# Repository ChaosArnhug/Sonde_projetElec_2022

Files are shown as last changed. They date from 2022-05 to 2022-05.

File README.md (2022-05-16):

# Projet d'électonique 2022
Ce répo regroupe le code, les schémas Eagle et le Prothéus du projet d'électonique à l'Ephec en 2022 pour les 2ièmes années.

## Contexte 

* Les PIC’s deviennent avec le temps des composants universels des systèmes électroniques et des systèmes embarqués. Il semble donc opportun que les étudiants soient aptes à définir et développer une carte comportant non seulement un microcontrôleur PIC mais aussi les composants annexes minimaux nécessaires au bon fonctionnement de ce dernier

*  De manière à pouvoir ensuite tester et vérifier le bon fonctionnement de la carte PIC, il semble opportun de développer une application électronique se basant, au moinspour certaines de ses fonctions, sur le PIC

* Cette application sera un télémètre à ultrasons qui envoie auPIC la mesure d’une distance en cm

* La carte doit afficher la distance sur 2 afficheurs 7-segments

* La carte devra signaler une alerte lorsque la distance dépasse (ou tombe en dessous d’) un seuil critique défini par l’utilisateur

* Enfin, pour utiliser les connaissances du cours de Développement informatique II, le PIC devra communiquer avec une application PYTHON qui affichera la distance
mesurée et permettra de définir le seuil de déclenchement d’alerte

## Spécifications

* PIC : 18F458

* Sonde : HC-SR04

* Affichage distance : 2 7-segments à cathodes communes 

* Affichage alerte : LED rouge qui clignote

* Affichage aucune alerte : LED verte

* Gestion du seuil : interface codée en Python

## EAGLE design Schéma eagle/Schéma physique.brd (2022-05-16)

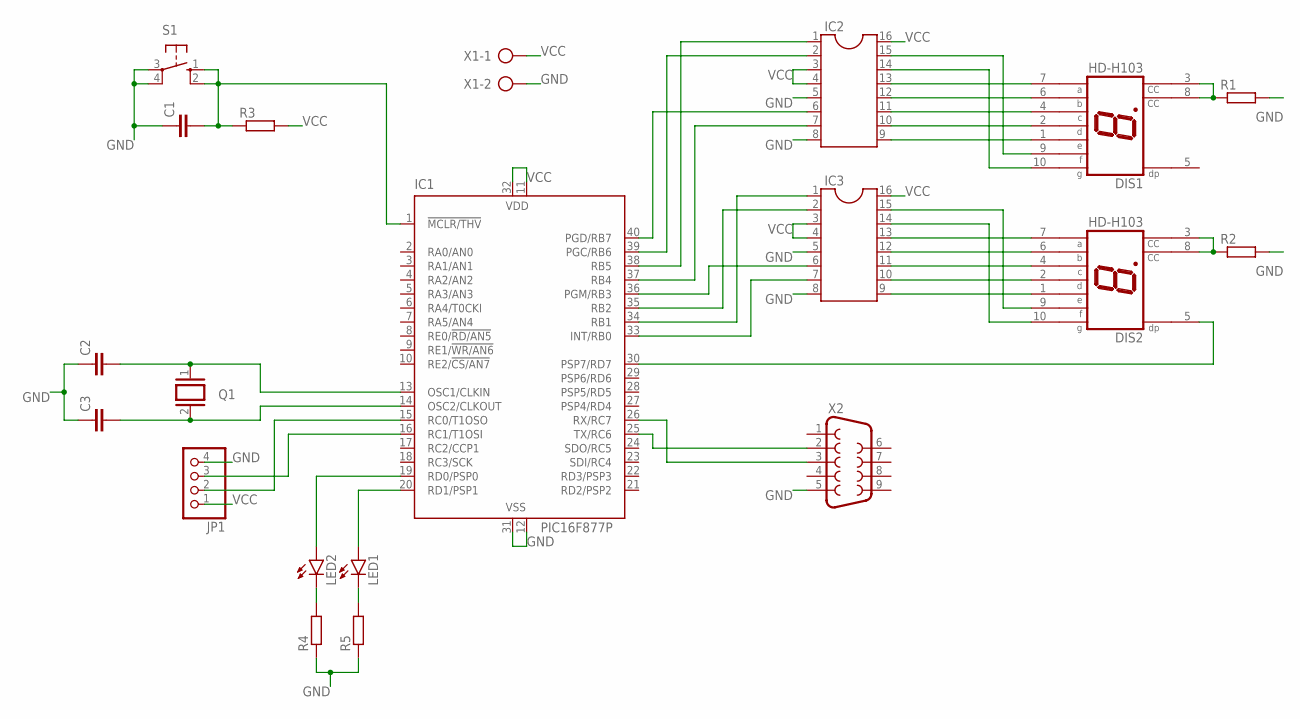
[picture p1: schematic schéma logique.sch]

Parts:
C1, C2, C3: C-EU025-025X050; C025-025X050
DIS1, DIS2: HD-H103; HDSP-M
IC1: PIC16F877P; DIL40
IC2, IC3: DIL16
JP1: PINHD-1X4; 1X04
LED1, LED2: LED5MM
Q1: XTAL/S; QS
R1, R2, R3, R4, R5: R-EU_0207/10; 0207/10
S1: 10-XX; B3F-10XX
X1: AK300/2
X2: F09H

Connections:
GND: C1.1, C2.1, C3.1, IC1.12 (VSS), IC1.31 (VSS), IC2.5, IC2.8, IC3.5, IC3.8, JP1.4, R1.2, R2.2, R4.1, R5.1, S1.3, S1.4 (P1), X1.2, X2.5
unnamed: IC1.25 (TX/RC6), X2.2
unnamed: IC1.26 (RX/RC7), X2.3
unnamed: IC1.33 (INT/RB0), IC3.7
unnamed: IC1.34 (RB1), IC3.1
unnamed: IC1.35 (RB2), IC3.2
unnamed: IC1.36 (PGM/RB3), IC3.6
unnamed: IC1.37 (RB4), IC2.7
unnamed: IC1.38 (RB5), IC2.1
unnamed: IC1.39 (PGC/RB6), IC2.2
unnamed: IC1.40 (PGD/RB7), IC2.6
unnamed: DIS1.7 (A), IC2.13
unnamed: DIS1.6 (B), IC2.12
unnamed: DIS1.4 (C), IC2.11
unnamed: DIS1.2 (D), IC2.10
unnamed: DIS1.1 (E), IC2.9
unnamed: DIS1.9 (F), IC2.15
unnamed: DIS1.10 (G), IC2.14
unnamed: DIS2.7 (A), IC3.13
unnamed: DIS2.6 (B), IC3.12
unnamed: DIS2.4 (C), IC3.11
unnamed: DIS2.2 (D), IC3.10
unnamed: DIS2.1 (E), IC3.9
unnamed: DIS2.9 (F), IC3.15
unnamed: DIS2.10 (G), IC3.14
unnamed: DIS1.3 (CC), DIS1.8 (CC), R1.1
unnamed: DIS2.3 (CC), DIS2.8 (CC), R2.1
unnamed: DIS2.5 (DP), IC1.30 (PSP7/RD7)
unnamed: C1.2, IC1.1 (!MCLR/THV), R3.1, S1.1 (S), S1.2 (S1)
unnamed: C2.2, IC1.13 (OSC1/CLKIN), Q1.1
unnamed: C3.2, IC1.14 (OSC2/CLKOUT), Q1.2
unnamed: IC1.15 (RC0/T1OSO), JP1.2
unnamed: IC1.16 (RC1/T1OSI), JP1.3
unnamed: IC1.19 (RD0/PSP0), LED2.A
unnamed: IC1.20 (RD1/PSP1), LED1.A
unnamed: LED2.K (C), R4.2
unnamed: LED1.K (C), R5.2
VCC: IC1.11 (VDD), IC1.32 (VDD), IC2.3, IC2.4, IC2.16, IC3.3, IC3.4, IC3.16, JP1.1, R3.2, X1.1

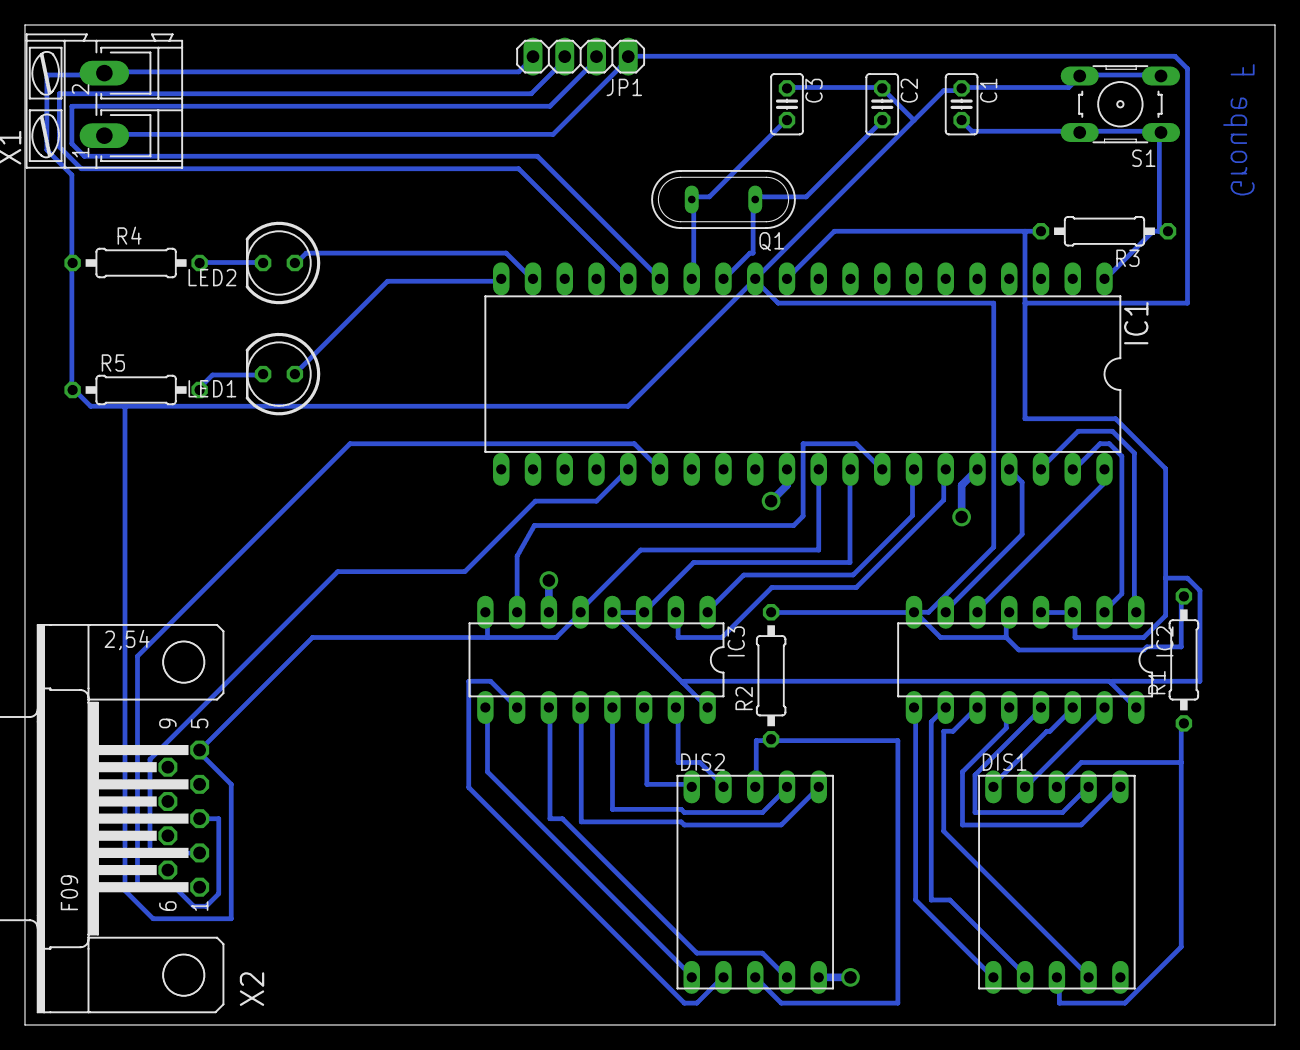
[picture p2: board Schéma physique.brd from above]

Board: 2 copper layers, 100.0 x 80.0 mm, 20 parts (0 on the bottom side), 38 nets.

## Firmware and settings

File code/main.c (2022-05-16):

#include <main.h>
#include <stdio.h>
#use rs232(baud=9600, xmit=PIN_C6, rcv=PIN_C7, ERRORS)

//communication avec port COM
int flag_threshold = 0; //flag on si nouveau seuil
char *buffer[4]; // 4 car cara dï¿½but trame + seuil (max = 999) ==> ex: @954 ou @001 ou @051
int buf_compteur = 0;
char *trame_start = "@";

#INT_RDA
void  RDA_isr(void)
{
   buffer[buf_compteur] = getc();   //lis le caractï¿½re ï¿½ la position courante du flux de donnï¿½es
   trame_start = buffer[0];
   if (strcmp(buffer[0], trame_start) == 0 && flag_threshold == 0){   //si trame commence par @ et qu'on ne traite pas dï¿½jï¿½ un nouveau seuil
      buf_compteur ++;
      if (buf_compteur >= 4){    //Traitement quand buffer plein
         buf_compteur = 0;
         flag_threshold = 1;
      }
   }
}

void main()
{
   //init variable
   int16 threshold;
   long duration;
   int16 distance;
   int poids_fort;
   int poids_faible;

   setup_timer_0(RTCC_INTERNAL);
   enable_interrupts(INT_RDA);
   enable_interrupts(GLOBAL);
   setup_low_volt_detect(FALSE);

   while(1)
   {
      //Initialization + être sure que trigger est off
      output_low(PIN_C0);
      delay_ms(300);
      
      //Prise d'une mesure
      output_high(PIN_C0);
      delay_us(300);
      output_low(PIN_C0);
      
      //Attend un output
      while(!input(PIN_C1)){}
      set_timer0(0);

      
      //Attend que l'output se termine
      while(input(PIN_C1)){}
      duration = (long)get_timer0();
      distance = (int16)(duration / 145);
      
          //Affichage
      if (distance >= 1000){ //Overflow ou distance négative = erreur
         output_b(0);
         output_high(PIN_D7); //affiche juste un point 

      }
      else if (distance >= 100){ // affichage passe en metre
         
         poids_fort = (int)(distance / 100);
         poids_faible = (int)((distance % 100) / 10);
         
         output_high(PIN_D7);
         output_b((poids_faible << 4) + poids_fort); //Decalage de 4 vers la doite à cause du montage physique et logique
 
      }
      else { //affichage en centimetre
      
         poids_fort = (int)distance / 10;
         poids_faible = (int)distance % 10;
         
         output_low(PIN_D7);
         output_b((poids_faible << 4) + poids_fort);
      }
      
      // Nouveau seuil
      if(flag_threshold){  //Calcul nouveau seuil (char - 48 => convert char to int)
         int16 a = buffer[1] - 48;
         int16 b = buffer[2] - 48;
         int16 c = buffer[3] - 48;
         threshold = (int16)((a*100)+(b*10)+c);
         flag_threshold = 0;

      } 
      
      if(threshold == NULL){  //valeur par defaut 
         threshold = 50;

      }
      
      //Alerte
      if(threshold < distance){
         output_high(PIN_D1); //alume led verte
         output_low(PIN_D0);

      }
      if(threshold > distance){
         output_low(PIN_D1); //Coupe led verte
         output_toggle(PIN_D0); //Clignote led red
       
      }
     
   }
}

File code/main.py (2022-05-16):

import tkinter.messagebox
from tkinter import *
import serial
import time
import threading

ser = serial.Serial('COM1', baudrate=9600, timeout=1)
run = True

'''
Functions ##############################################################################################################
'''


def writeOnPort():
    resp = e1.get()
    if (verifString(resp) == True):
        ser.write(resp.encode())
        tkinter.messagebox.showinfo(title="Réussi !", message="Le nouveau seuil de déclenchement à été défini !")
    else :
        tkinter.messagebox.showwarning(title="Erreur", message="Le seuil de déclenchement doit être écris de cette manière :\n @123 \n(si la valeur est inférieur à 100cm, il faut indiquer un 0 (exemple : 090) \n ATTENTION : La valeur ne doit pas excéder 400cm !")
    print(resp)


def verifString(test):
    test_sans = test[1:] # sans le @
    if ((test.startswith("@")) == True & (test_sans.isdecimal()) == True & (len(test) == 4) == True): #soucis sans les True, les tests ne passaient pas
        if ((int(test_sans) <= 400) == True): #vérification en 2 if car soucis de changement de type avec int
            return True
    else:
        return False


def readOnPort():
    if run:
        data_received = (ser.read(3)).decode()
        test_data = data_received
        print(test_data)
        if ((test_data.isdigit()) == True):
            distance_label.config(text=f"La distance actuelle est de : {test_data}")
        if (test_data == "ON_"):
            frame1.config(bg='#e64221')
            alerte_label.config(bg='#e64221')
        if (test_data == "OFF"):
            frame1.config(bg='#66e341')
            alerte_label.config(bg='#66e341')
        root.after(1000, readOnPort)


def stopRead():
    global run
    run = False
    print("stop")


#def startRead():
#    global run
#    run = True
#    readOnPort


'''
Graphical User Interface ###############################################################################################
'''

root = Tk()

root.title("Test")
root.geometry("600x500")

my_label = Label(root, text="Seuil de déclenchement")
my_label.pack(pady=20)

frame1 = Frame(root, borderwidth=2, relief=GROOVE)
frame1.pack(side=BOTTOM, padx=10, pady=10)
alerte_label = Label(frame1, text="Alerte")
alerte_label.pack(pady=10, padx=10)

e1 = Entry(root)
e1.pack(pady=20)

my_button1 = Button(root, text="Ajouter", command=writeOnPort)
my_button1.pack(pady=20)

distance_label = Label(root, text="")
distance_label.pack(pady=20)

my_button2 = Button(root, text="Read", command=threading.Thread(target=readOnPort).start)
my_button2.pack(pady=20)

my_button3 = Button(root, text="Stop", command=stopRead)
my_button3.pack(pady=20)

#my_button4 = Button(root, text="Start", command=threading.Thread(target=startRead).start)
#my_button4.pack(padx=20)

root.mainloop()

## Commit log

2022-05-13 code final 2.1
    Plus besoin de la librairie stdlib.h
2022-05-16 Ajout du code
    Le code est entièrement fonctionnel sauf pour le problème de latence avec les données reçues pour l'alerte. (Temps record : 1"47"14)
2022-05-16 Rename Groupe F.brd to Schéma physique.brd
    [Schéma physique.brd]
2022-05-16 Rename schéma eagle.sch to schéma logique.sch
    [schéma eagle.sch, schéma logique.sch]
